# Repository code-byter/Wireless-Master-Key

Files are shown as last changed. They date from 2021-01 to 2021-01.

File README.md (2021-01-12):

# Wireless-Master-Key
Exploiting Software-Defined Radio - Common attacks and a device to exploit them (Proof of Concept).

Software-Defined Radio is used in a broad variety of applications. One of them is a wireless remote, like your garage door remote or your car-key fob. These devices can be hacked easily. Some basic, but effective, attacks are presented in this project. The Wireless Master Key is  a small DIY device, based on an ESP8266 and the Arduino platform, which serves as a proof of concept.

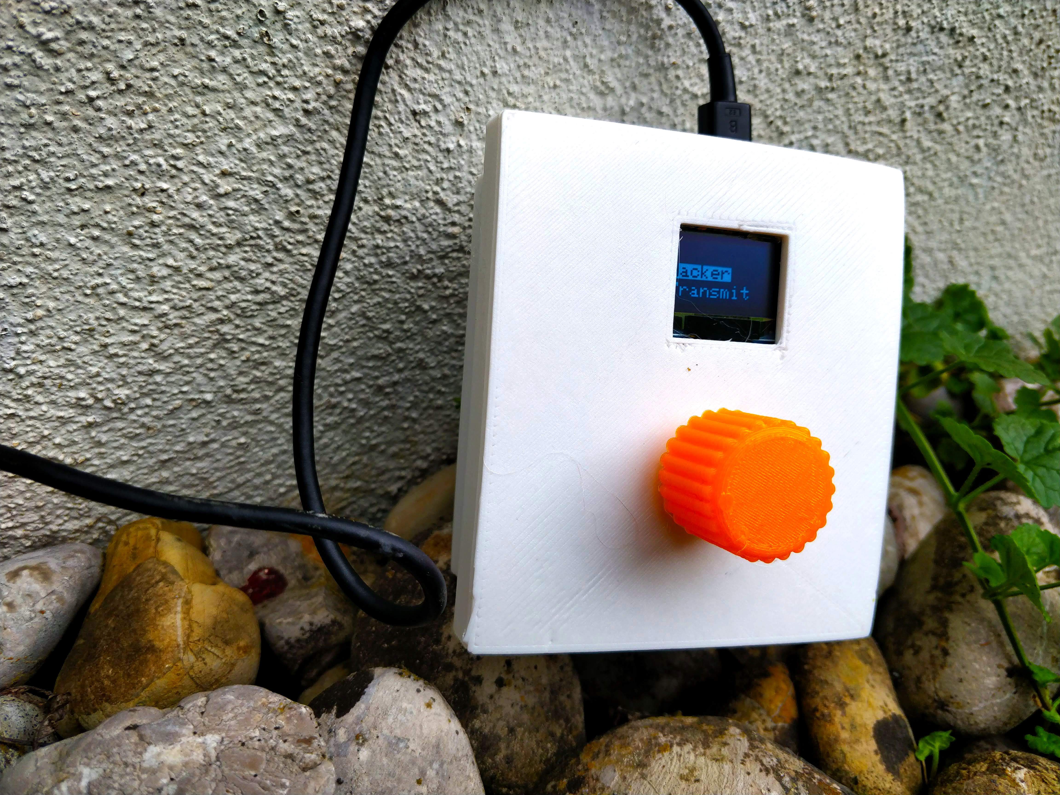
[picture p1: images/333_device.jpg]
Wireless master key


Functionality:
This device has the following features:
- Receiving, Decoding and Displaying Signals
- Replaying Signals
- Transmitting custom signals

A detailed description can be found in ```paper.pdf```

# Disclaimer
This project is is only for educational purposes and serves as a proof of concept.
Neither the ESP8266, nor the other parts were meant or built for such purposes. Bugs can occur!

Use it only against your own devices!
Please check the legal regulations in your country before using it.
I don't take any responsibility for what you do with this project.

# Hardware
The Wireless Master Key operates within the 433MHz frequency band. It uses a reciever and two transmitters (But the second transmitter is optional). The user interface consists of an OLED-Display and a Rotary Encoder.
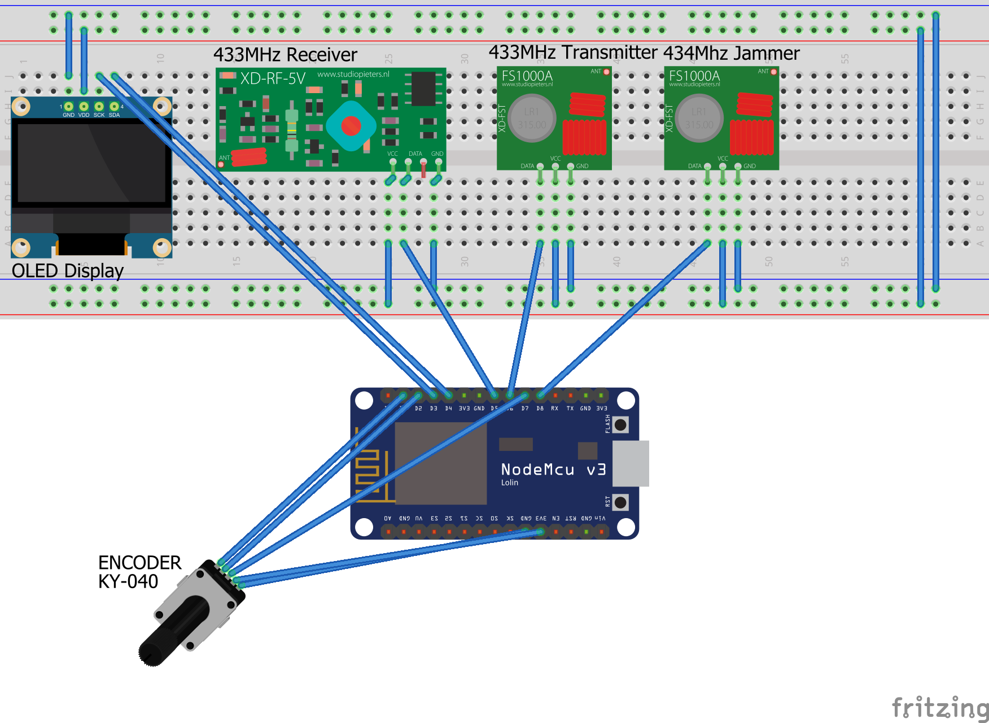
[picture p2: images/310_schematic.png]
Schematic


Device Pin  | NodeMCU Pin
----------- | ------------
Receiver    | D5
Transmitter | D6
Jammer      | D8
SCL         | D3
SDA         | D4
CLK         | D1
DT          | D2
SW          | D7

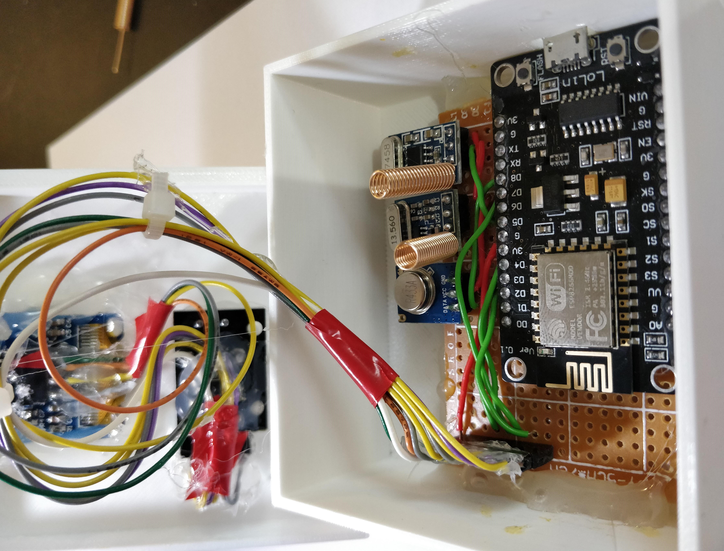
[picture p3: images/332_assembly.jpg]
Electronics


# Software
The following libraries need to be installed.
```
Adafruit_GFX.h
Adafruit_SSD1306.h
RCSwitch.h
Encoder.h
```

The ```code.ino``` files contains all the necessary code to programm the ESP8266. This can be done by using the Arduino IDE. The code, that's necessary for transmitting the signals is left out.

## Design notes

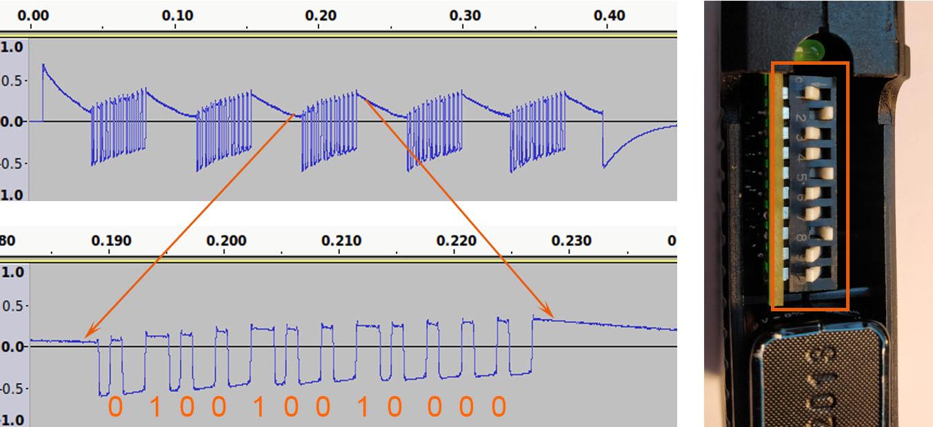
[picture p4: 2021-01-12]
images/230_DIP.jpg

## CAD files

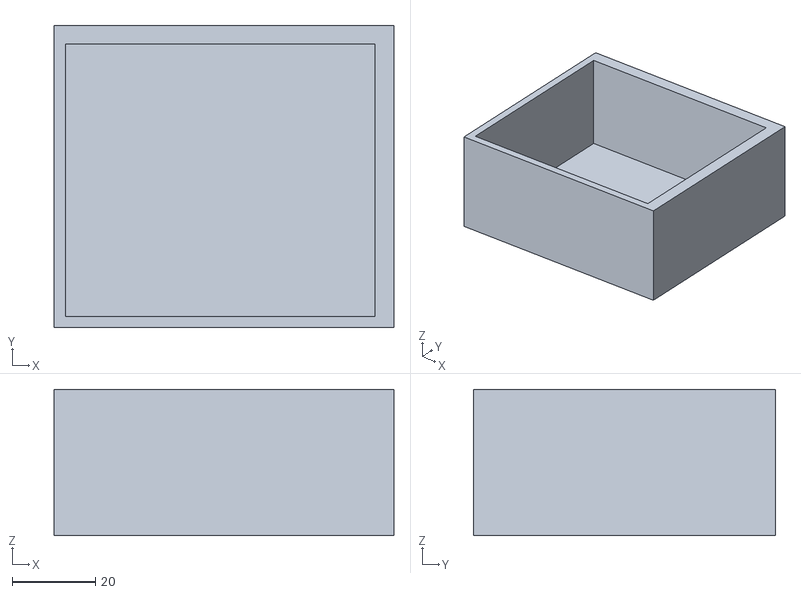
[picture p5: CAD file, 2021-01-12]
case_bottom.stl
81.5 x 72.5 x 35.0

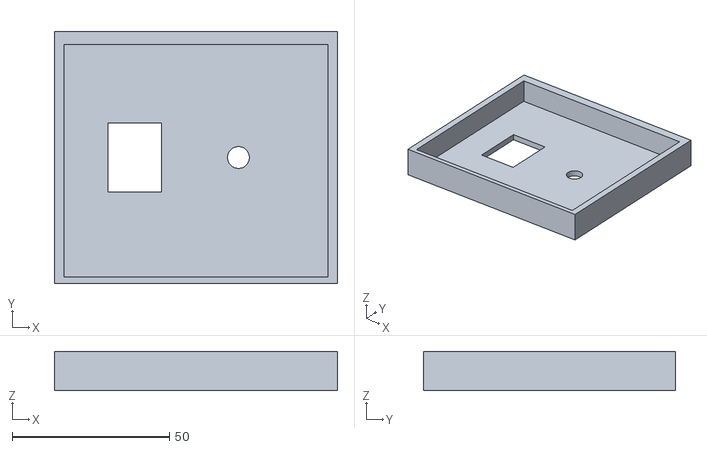
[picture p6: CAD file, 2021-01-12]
case_top.stl
90.0 x 80.0 x 12.5

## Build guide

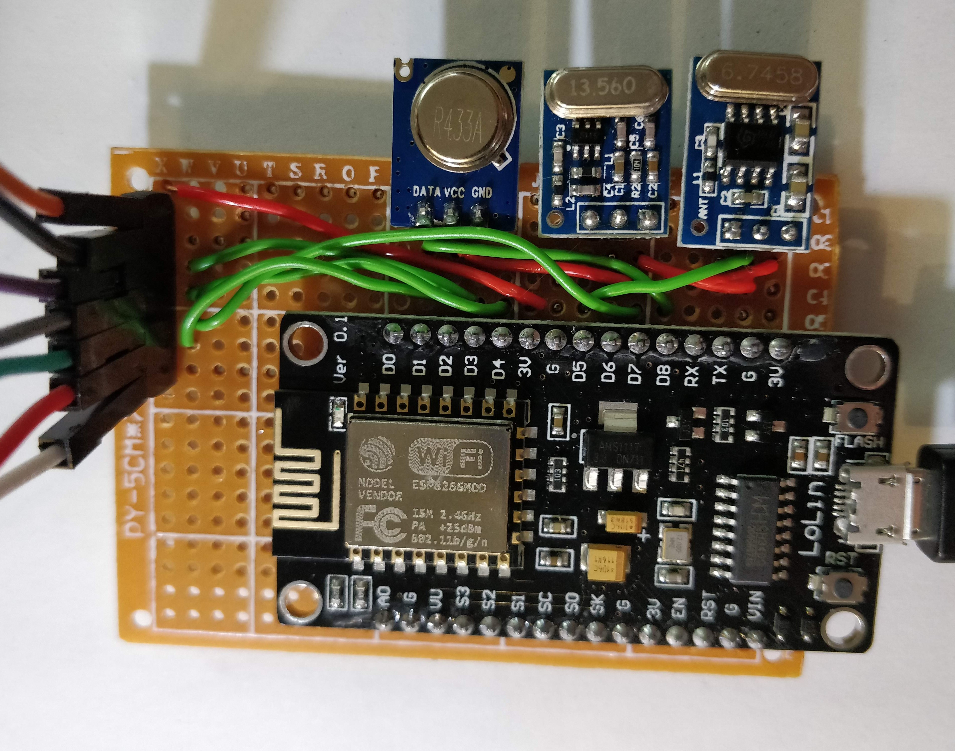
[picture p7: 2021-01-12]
images/330_soldering.jpg

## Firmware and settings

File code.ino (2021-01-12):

#include <Arduino.h>
#include <Wire.h>
#include <SPI.h>
#include <Adafruit_GFX.h>
#include <Adafruit_SSD1306.h>
#include <RCSwitch.h>
#include <Encoder.h>

/*
 * Pinout
 * -------------------------------------------------------
 * -------------------------------------------------------
 * Receiver     D5
 * Transmitter  D6
 * Jammer       D8
 * 
 * SCL          D3
 * SDA          D4
 * 
 * CLK          D1
 * DT           D2
 * SW           D7
 * 
 */
Adafruit_SSD1306 display(-1);

Encoder encoder(D1, D2);
RCSwitch receiver = RCSwitch();
RCSwitch transmitter = RCSwitch();
RCSwitch jammer = RCSwitch();

long oldPosition = -999;
boolean isButtonPressed = false;
long lastUpdateMillis = 0;

#define menuLength 5
String menuOptions[] = {"||Wmk433||", "Jammer", "Sniffer", "Spoofer", "Hacker", "Transmit"};
int menuPosition = 0;

void handleKey()
{
  isButtonPressed = true;
}

void printLine(String message, int line, bool inverted)
{
  display.setTextSize(2);
  if (!inverted)
    display.setTextColor(WHITE);
  else
    display.setTextColor(BLACK, WHITE);
  display.setCursor(0, 20 * line + 4);
  display.println(message);
}

void displayMenu()
{
  display.clearDisplay();
  display.display();

  if (menuPosition == 0)
  {
    printLine(menuOptions[0], 0, false);
    printLine(menuOptions[1], 1, false);
    printLine(menuOptions[2], 2, false);
  }
  else if (menuPosition == menuLength)
  {
    printLine(menuOptions[menuLength - 2], 0, false);
    printLine(menuOptions[menuLength - 1], 1, false);
    printLine(menuOptions[menuLength], 2, true);
  }
  else
  {
    printLine(menuOptions[menuPosition - 1], 0, false);
    printLine(menuOptions[menuPosition], 1, true);
    printLine(menuOptions[menuPosition + 1], 2, false);
  }
  display.display();
}

//return true if button is pressed and return the main-menu
bool exitOption()
{
  if (isButtonPressed)
  {
    delay(10);
    isButtonPressed = false;
    displayMenu();
    return true;
  }
  return false;
}

void initJammer()
{
  //Init Display
  display.clearDisplay();
  display.setTextSize(2);
  display.setTextColor(WHITE);
  display.setCursor(0, 0);
  display.println("Jammer");

  display.setTextSize(2);
  display.setTextColor(BLACK, WHITE);
  display.setCursor(115, 0);
  display.println("X");

  display.setTextSize(2);
  display.setTextColor(WHITE);
  display.setCursor(0, 25);
  display.println("Jamming ...");
  display.display();

  //Start jamming
  while (!exitOption())
  {
    delay(30);
  }
}

//Display the Sniffer Headline on the Display
void displaySniffer()
{
  display.clearDisplay();
  display.setTextSize(2);
  display.setTextColor(WHITE);
  display.setCursor(0, 0);
  display.println("Sniffer");

  display.setTextSize(2);
  display.setTextColor(BLACK, WHITE);
  display.setCursor(115, 0);
  display.println("X");
  display.display();
}

void initSniffer()
{
  displaySniffer();

  //Receiving and displaying data in this loop
  while (!exitOption())
  {
    if (receiver.available())
    {
      display.clearDisplay();
      displaySniffer();

      display.setTextSize(2);
      display.setTextColor(WHITE);
      display.setCursor(0, 22);
      display.println(receiver.getReceivedValue());

      display.setTextSize(1);
      display.setTextColor(WHITE);
      display.setCursor(0, 42);
      display.println(receiver.getReceivedBitlength());
      display.setCursor(12, 42);
      display.println("bit");
      display.setCursor(40, 42);
      display.println(receiver.getReceivedDelay());
      display.setCursor(58, 42);
      display.println("us");
      display.display();
      receiver.resetAvailable();
    }
    delay(5);
  }
}

void spoofer()
{
  //Received Signal is stored here
  long receivedValue = 0;
  int receivedBitlength = 0;
  int receivedDelay = 0;
  int receivedProtocol = 0;

  //Init Display
  display.clearDisplay();
  display.setTextSize(2);
  display.setTextColor(WHITE);
  display.setCursor(0, 0);
  display.println("Spoofer");

  display.setTextSize(2);
  display.setTextColor(BLACK, WHITE);
  display.setCursor(115, 0);
  display.println("X");
  display.display();

  //Listen for signals
  receiver.resetAvailable();
  bool scanning = true;
  bool transmitting = false;
  while (scanning)
  {
    if (receiver.available())
    {
      receivedValue = receiver.getReceivedValue();
      receivedBitlength = receiver.getReceivedBitlength();
      receivedDelay = receiver.getReceivedDelay();
      receivedProtocol = receiver.getReceivedProtocol();
      receiver.resetAvailable();
      scanning = false;
      //Signal is received and stored
    }
    if (isButtonPressed) //Abort Sacanning
    {
      delay(30);
      isButtonPressed = false;
      displayMenu();
      return;
    }
    delay(10);
  }

  //Display Signal
  int selectedOption = 0;
  bool update = true;
  while (!scanning)
  {
    long newPosition = encoder.read(); //Handle menu ooptions
    if (newPosition != oldPosition)
    {
      if ((newPosition % 4 == 0) && ((newPosition - oldPosition) > 0))
      {
        if (selectedOption < 2)
        {
          selectedOption += 1;
          update = true;
        }
        else
          selectedOption = 0;
      }
      else if ((newPosition % 4 == 0) && ((newPosition - oldPosition) < 0))
      {
        if (selectedOption > 0)
        {
          selectedOption -= 1;
          update = true;
        }
        else
          selectedOption = 2;
      }
      oldPosition = newPosition;
    }

    if (update) //Display Signal
    {
      display.clearDisplay();
      display.setTextSize(2);
      display.setTextColor(WHITE);
      display.setCursor(0, 7);
      display.println(receivedValue);

      display.setTextSize(1);
      display.setTextColor(WHITE);
      display.setCursor(0, 27);
      display.println(receivedBitlength);
      display.setCursor(12, 27);
      display.println("bit");
      display.setCursor(40, 27);
      display.println(receivedDelay);
      display.setCursor(58, 27);
      display.println("us");

      if (selectedOption == 0)
        display.setTextColor(BLACK, WHITE);
      else
        display.setTextColor(WHITE);
      display.setCursor(0, 50);
      display.println("Send");
      if (selectedOption == 1)
        display.setTextColor(BLACK, WHITE);
      else
        display.setTextColor(WHITE);
      display.setCursor(42, 50);
      display.println("Search");
      if (selectedOption == 2)
        display.setTextColor(BLACK, WHITE);
      else
        display.setTextColor(WHITE);
      display.setCursor(95, 50);
      display.println("Exit");
      display.display();
    }
    if (isButtonPressed)
    {
      isButtonPressed = false;
      scanning = true;
      delay(30);
      if (selectedOption == 0)
        transmitting = true;
      if (selectedOption == 1)
        spoofer();
      if (selectedOption == 2)
      {
        displayMenu();
      }
    }
    delay(10);
  }

  //Transnmit signal
  if (transmitting)
  {
    display.clearDisplay();
    display.setTextSize(2);
    display.setTextColor(WHITE);
    display.setCursor(0, 15);
    display.println("Transmitting ...");
    display.display();

    while (!exitOption())
    {
      jammer.setPulseLength(receivedDelay);
      jammer.setProtocol(receivedProtocol);
      delay(50);
    }
  }
  displayMenu();
}

void initHacker() //brute-force attack
{
  display.clearDisplay();
  display.setTextSize(2);
  display.setTextColor(WHITE);
  display.setCursor(0, 0);
  display.println("Hacker");

  display.setTextSize(2);
  display.setTextColor(BLACK, WHITE);
  display.setCursor(115, 0);
  display.println("X");

  display.setTextSize(2);
  display.setTextColor(WHITE);
  display.setCursor(0, 25);
  display.println("Hacking...");
  display.display();

  jammer.setRepeatTransmit(2);
  int bitlength = 8;
  int maxlength = 256; //2^8
  for (int i = 0; i <= maxlength; i++)
  {
    delay(10);
    Serial.println(i);
    if (exitOption())
      break;
  }
  displayMenu();
}

int readSerialInt()
{
  int value = 0;
  while (!exitOption())
  {
    while (Serial.available())
    {
      char inChar = (char)Serial.read();
      if ((inChar >= '0') && (inChar <= '9'))
      {
        Serial.print(inChar);
        value = value * 10 + inChar - '0';
      }
      if (inChar == '\n')
      {
        return value;
      }
    }
  }
  return 0;
}

void initTransmit()
{
  display.clearDisplay();
  display.setTextSize(2);
  display.setTextColor(WHITE);
  display.setCursor(0, 0);
  display.println("Transmit");

  display.setTextSize(2);
  display.setTextColor(BLACK, WHITE);
  display.setCursor(115, 0);
  display.println("X");

  display.setTextSize(1);
  display.setTextColor(WHITE);
  display.setCursor(0, 25);
  display.println("Connect your PC and  open the Serial      Monitor!");
  display.display();

  Serial.println("Welcome to the wmk433");
  Serial.println("Please enter the binary code");

  unsigned long code = 0;
  int pulseLength = 0;
  int protocol = 0;
  int bitlength = 0;
  Serial.println("\nCode in dezimal: ");
  code = readSerialInt();
  if (!(code))
    return;
  Serial.println("\nNumber of bits: ");
  bitlength = readSerialInt();
  if (!(bitlength))
    return;
  Serial.println("\nDelay per bit: ");
  pulseLength = readSerialInt();
  if (!(pulseLength))
    return;
  Serial.println("\nProtocol: ");
  protocol = readSerialInt();
  if (!(protocol))
    return;
  jammer.setProtocol(protocol);
  jammer.setPulseLength(pulseLength);
  jammer.setRepeatTransmit(60);
  Serial.println("\nTransmitting ...");
}

void setup()
{
  Wire.begin(D4, D3); //Init communications standards
  Serial.begin(9600);

  jammer.enableTransmit(D8); //Init 433MHz equipment
  transmitter.enableTransmit(D6);
  receiver.enableReceive(D5);

  pinMode(D7, INPUT_PULLUP); //Init Encoder
  attachInterrupt(D7, handleKey, RISING);

  display.begin(SSD1306_SWITCHCAPVCC, 0x3C); // Init Display with the I2C addr 0x3C (128x64) //SSD1306_SWITCHCAPVCC
  display.clearDisplay();
  display.display();

  display.setTextSize(1);
  display.setTextColor(WHITE);
  display.setCursor(0, 0);
  display.println("@code_byter");
  display.display();
  display.setTextSize(1);
  display.setTextColor(BLACK, WHITE);
  display.setCursor(0, 8);
  display.println("@code_byter");
  display.display();
  display.setTextSize(1);
  display.setTextColor(WHITE);
  display.setCursor(0, 24);
  display.println("@code_byter");
  display.display();

  Serial.println("RF-Hacker connected ...");
  displayMenu();
}

void loop()
{
  long newPosition = encoder.read();

  if (newPosition != oldPosition)
  {
    if ((newPosition % 4 == 0) && ((newPosition - oldPosition) > 0))
    {
      if (menuPosition < menuLength)
        menuPosition += 1;
      displayMenu();
    }
    else if ((newPosition % 4 == 0) && ((newPosition - oldPosition) < 0))
    {
      if (menuPosition > 0)
        menuPosition -= 1;
      displayMenu();
    }
    oldPosition = newPosition;
  }

  if (isButtonPressed)
  {
    isButtonPressed = false;
    delay(30);
    if (menuPosition == 2)
    {
      initSniffer();
    }
    else if (menuPosition == 1)
    {
      initJammer();
    }
    else if (menuPosition == 3)
    {
      spoofer();
    }
    else if (menuPosition == 4)
    {
      initHacker();
    }
    else if (menuPosition == 5)
    {
      initTransmit();
    }
  }
}
